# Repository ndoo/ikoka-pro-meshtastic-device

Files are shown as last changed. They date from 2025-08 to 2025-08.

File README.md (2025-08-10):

# Ikoka Pro Meshtastic Device

* Eurocard form factor
  * Half Eurocard - 100 mm × 80mm
  * All I/O in front
* Nordic nrf52840 MCU (EBYTE E73-2G4M08S1C module)
* EBYTE E22 LoRa module (22/30/33 dBm)
* Quectel L76K GPS
* Up to 1.5A solar/DC charging

## PCB Renders

### PCB Top

top

### PCB Bottom

bottom

### Rotating GIF

animation

(Rendered with [kicad-render](https://github.com/linalinn/kicad-render).)

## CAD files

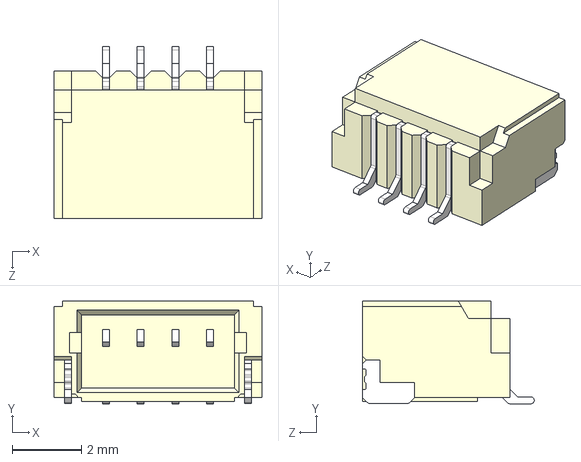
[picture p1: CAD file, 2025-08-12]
3dmodels/SM04B-SRSS-TB (LF)(SN)--3DModel-STEP-269445.STEP
6.00 x 2.96 x 4.95 mm

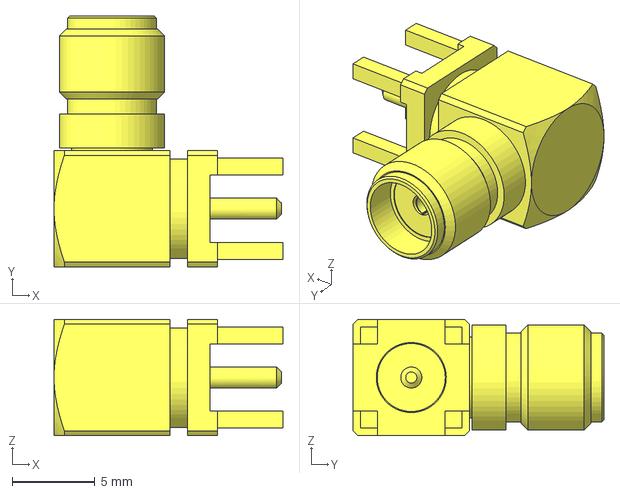
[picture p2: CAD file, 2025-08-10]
3dmodels/SMA-J-P-H-RA-TH1.stp
13.8 x 15.1 x 7.00 mm

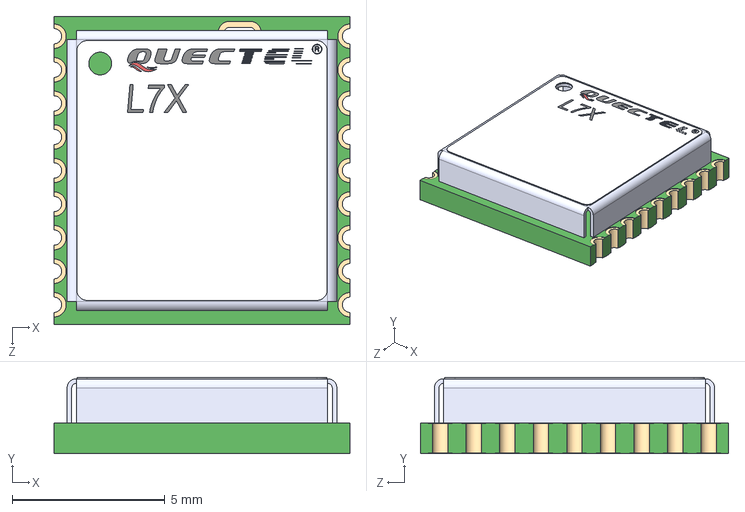
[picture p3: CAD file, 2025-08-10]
3dmodels/L76.STEP
9.70 x 2.49 x 10.1 mm

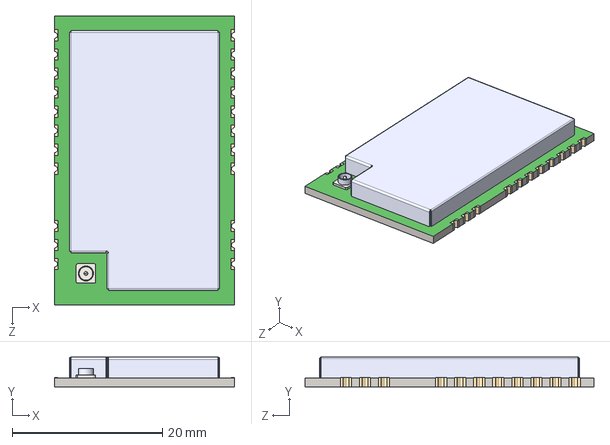
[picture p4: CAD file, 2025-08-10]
3dmodels/E22-900M30S.step
24.0 x 3.97 x 38.5 mm

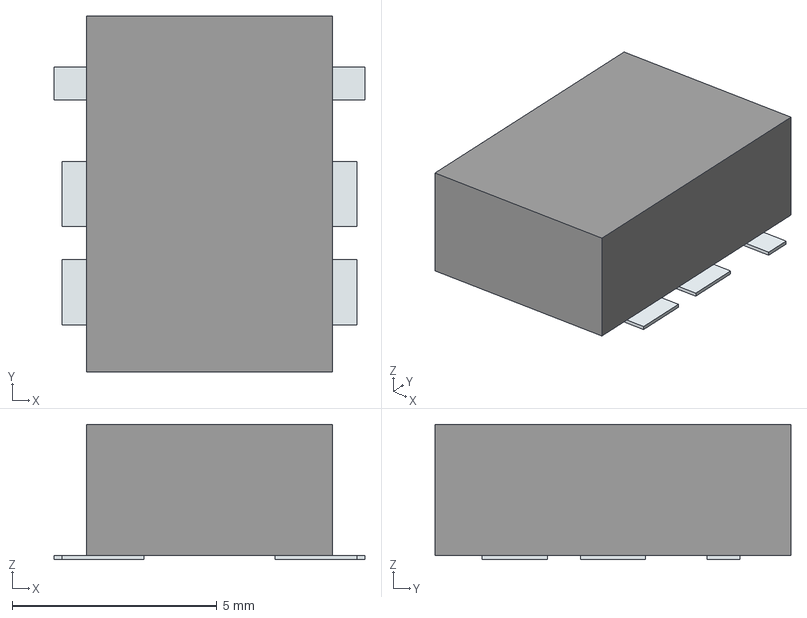
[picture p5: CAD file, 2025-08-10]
3dmodels/DBP.915.V.A.30.stp
7.60 x 8.70 x 3.30 mm
Pins

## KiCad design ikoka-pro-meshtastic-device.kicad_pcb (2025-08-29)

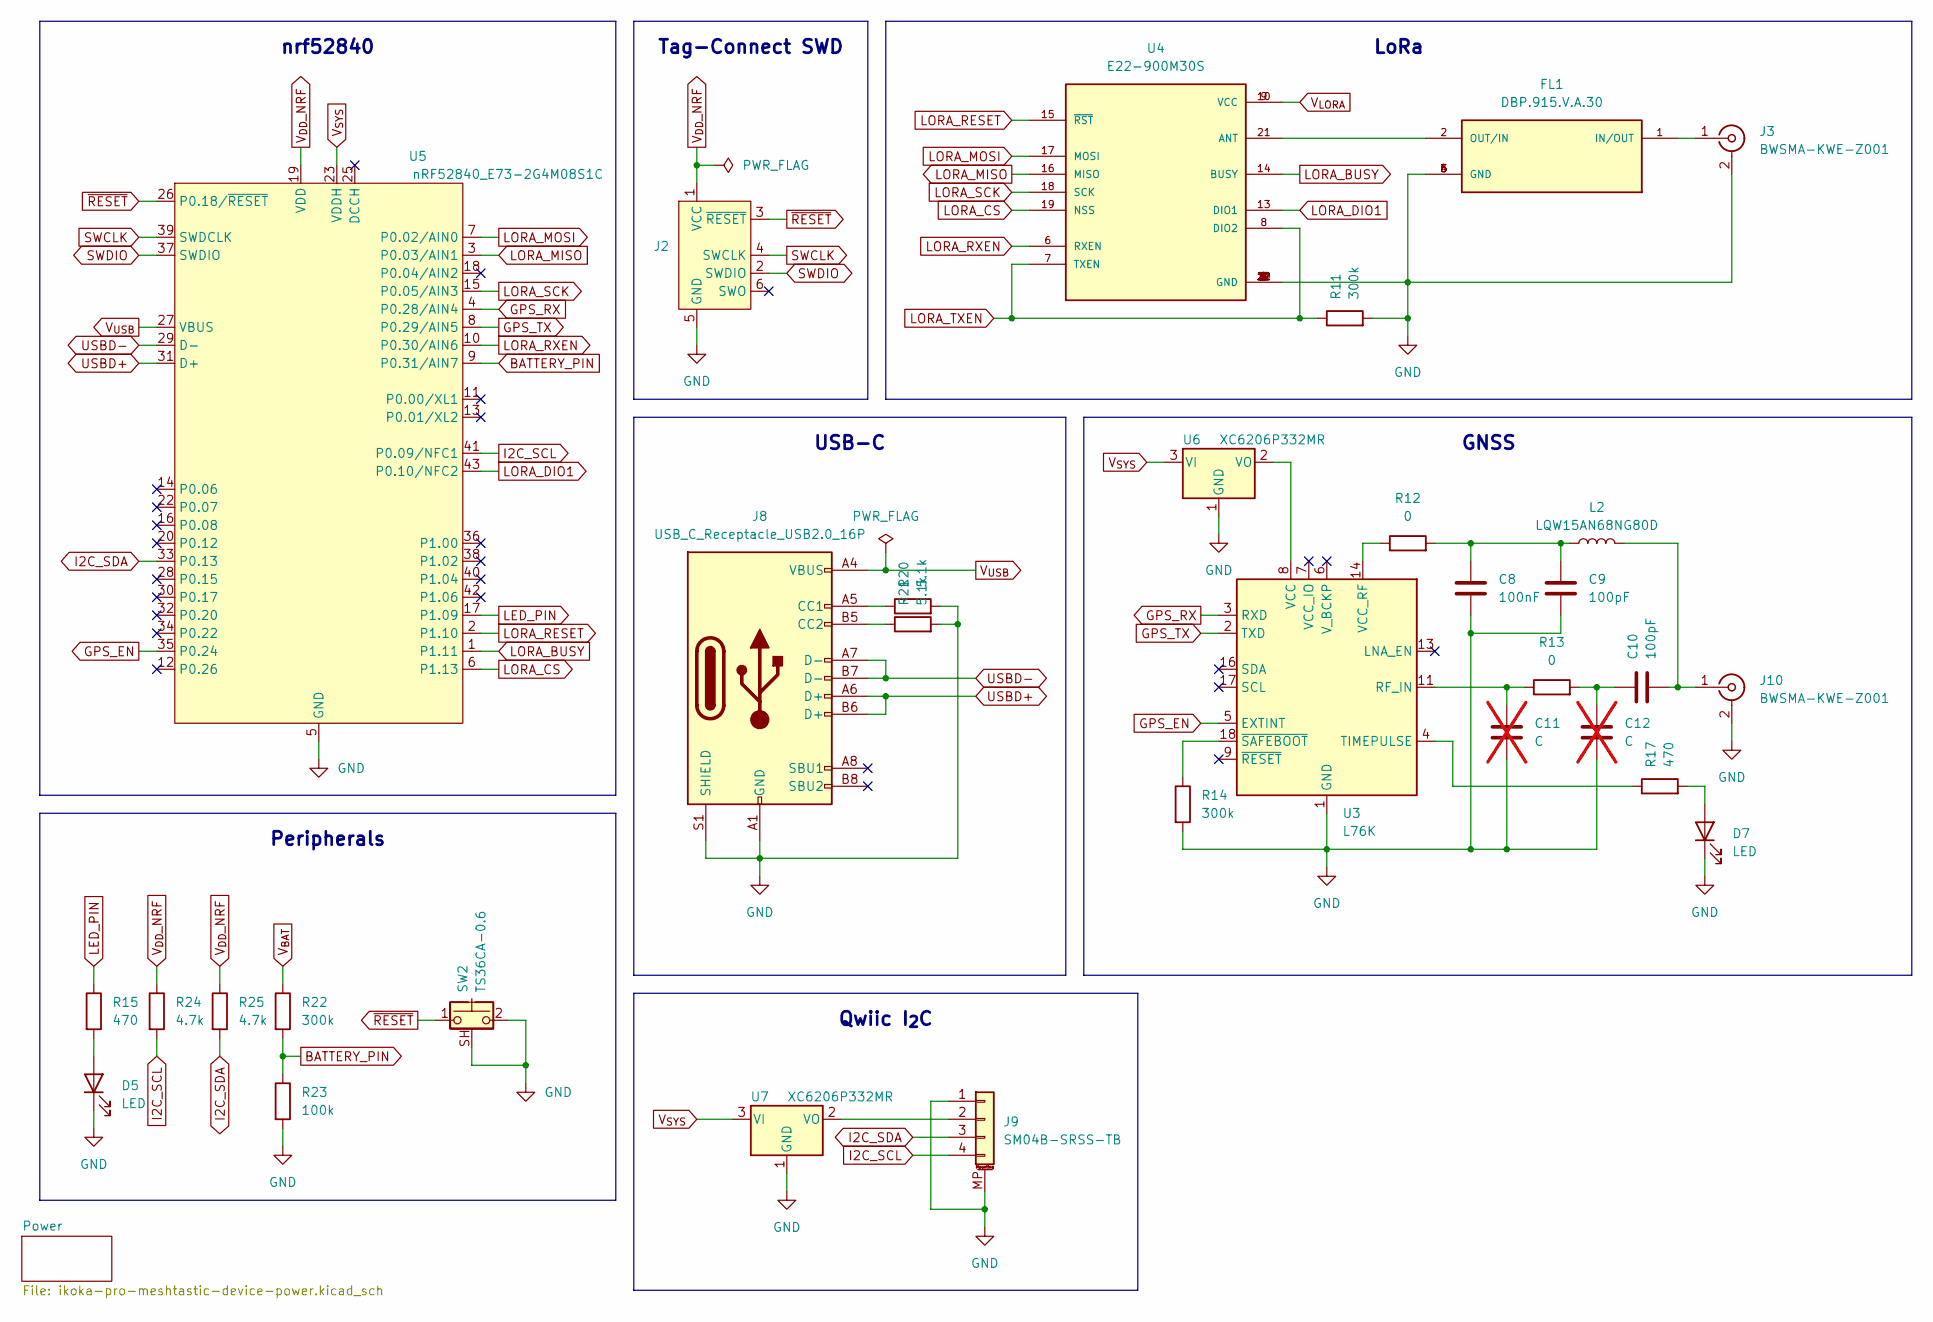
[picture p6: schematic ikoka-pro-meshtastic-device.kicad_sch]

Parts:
C8: 100nF; C_0402_1005Metric; MPN CL10A226MQ8NRNC; LCSC C307331
C9, C10: 100pF; C_0402_1005Metric; MPN CL10A226MQ8NRNC; LCSC C1546
C11, C12: C; C_0402_1005Metric; MPN CL10A226MQ8NRNC; LCSC C59461; not fitted
D5, D7: LED; LED_0603_1608Metric; LCSC C2290
FL1: DBP.915.V.A.30; FIL_DBP.915.V.A.30; PARTREV SPE-17-8-060/B/AW; LCSC C3155564
J2: Conn_ARM_JTAG_SWD_10; CON_TC2030_outlined
J3, J10: BWSMA-KWE-Z001; SMA_BAT_Wireless_BWSMA-KWE-Z001; LCSC C496551
J8: USB_C_Receptacle_USB2.0_16P; USB_C_Receptacle_G-Switch_GT-USB-7051x; LCSC C2843970
J9: SM04B-SRSS-TB; JST_SH_SM04B-SRSS-TB_1x04-1MP_P1.00mm_Horizontal; LCSC C160404
L2: LQW15AN68NG80D; L_0402_1005Metric; LCSC C3221844
R11, R14, R22: 300k; R_0402_1005Metric; LCSC C25774
R12, R13: 0; R_0402_1005Metric; LCSC C17168
R15, R17: 470; R_0402_1005Metric; LCSC C25117
R20, R21: 5.1k; R_0402_1005Metric; LCSC C25905
R23: 100k; R_0402_1005Metric; LCSC C25741
R24, R25: 4.7k; R_0402_1005Metric; LCSC C25900
SW2: TS36CA-0.6; SW_SPST_TS36CA-0.6; LCSC C2906288
U3: L76K; ublox_MAX; LCSC C2916234
U4: E22-900M30S; XCVR_E22-900M30S; PARTREV 1.2; LCSC C411294
U5: nRF52840_E73-2G4M08S1C; LCSC C356849
U6, U7: XC6206P332MR; SOT-23-3; LCSC C5446

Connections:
BATTERY_PIN: R22.2, R23.1, U5.9 (P0.31/AIN7)
GND: C8.2, C9.2, C11.2, C12.2, D5.1 (K), D7.1 (K), FL1.3 (GND), FL1.4 (GND), FL1.5 (GND), FL1.6 (GND), J2.5 (GND), J3.2 (Ext), J8.A1 (GND), J8.A12 (GND), J8.B1 (GND), J8.B12 (GND), J8.S1 (SHIELD), J9.1, J9.MP (MountPin), J10.2 (Ext), R11.2, R14.2, R20.2, R21.2, R23.2, SW2.2, SW2.SH (B), U3.1 (GND), U3.10 (GND), U3.12 (GND), U4.1 (GND), U4.2 (GND), U4.3 (GND), U4.4 (GND), U4.5 (GND), U4.11 (GND), U4.12 (GND), U4.20 (GND), U4.22 (GND), U5.5 (GND), U5.21 (GND), U5.24 (GND), U6.1 (GND), U7.1 (GND); also elsewhere on the board
GPS_EN: U3.5 (EXTINT), U5.35 (P0.24)
GPS_RX: U3.3 (RXD), U5.4 (P0.28/AIN4)
GPS_TX: U3.2 (TXD), U5.8 (P0.29/AIN5)
I2C_SCL: J9.4, R24.2, U5.41 (P0.09/NFC1)
I2C_SDA: J9.3, R25.2, U5.33 (P0.13)
LED_PIN: R15.1, U5.17 (P1.09)
LORA_BUSY: U4.14 (BUSY), U5.1 (P1.11)
LORA_CS: U4.19 (NSS), U5.6 (P1.13)
LORA_DIO1: U4.13 (DIO1), U5.43 (P0.10/NFC2)
LORA_MISO: U4.16 (MISO), U5.3 (P0.03/AIN1)
LORA_MOSI: U4.17 (MOSI), U5.7 (P0.02/AIN0)
LORA_RESET: U4.15 (~RST), U5.2 (P1.10); also elsewhere on the board
LORA_RXEN: U4.6 (RXEN), U5.10 (P0.30/AIN6)
LORA_SCK: U4.18 (SCK), U5.15 (P0.05/AIN3)
LORA_TXEN: R11.1, U4.7 (TXEN), U4.8 (DIO2)
unnamed: C8.1, C9.1, L2.1, R12.2
unnamed: C10.1, C12.1, R13.2
unnamed: D5.2 (A), R15.2
unnamed: D7.2 (A), R17.2
unnamed: FL1.1 (IN/OUT), J3.1 (In)
unnamed: FL1.2 (OUT/IN), U4.21 (ANT)
unnamed: J8.A5 (CC1), R20.1
unnamed: J8.B5 (CC2), R21.1
unnamed: J9.2, U7.2 (VO)
unnamed: C10.2, J10.1 (In), L2.2
unnamed: C11.1, R13.1, U3.11 (RF_IN)
unnamed: R17.1, U3.4 (TIMEPULSE)
unnamed: U3.8 (VCC), U6.2 (VO)
unnamed: R12.1, U3.14 (VCC_RF)
unnamed: R14.1, U3.18 (~SAFEBOOT)
SWCLK: J2.4 (SWCLK), U5.39 (SWDCLK)
SWDIO: J2.2 (SWDIO), U5.37 (SWDIO)
USBD+: J8.A6 (D+), J8.B6 (D+), U5.31 (D+)
USBD-: J8.A7 (D-), J8.B7 (D-), U5.29 (D-)
V_{BAT}: R22.1; also elsewhere on the board
V_{DD}_NRF: J2.1 (VCC), R24.1, R25.1, U5.19 (VDD)
V_{LORA}: U4.9 (VCC), U4.10 (VCC); also elsewhere on the board
V_{SYS}: U5.23 (VDDH), U6.3 (VI), U7.3 (VI); also elsewhere on the board
V_{USB}: J8.A4 (VBUS), J8.A9 (VBUS), J8.B4 (VBUS), J8.B9 (VBUS), U5.27 (VBUS)
~RESET: J2.3 (~RESET), SW2.1, U5.26 (P0.18/~RESET)

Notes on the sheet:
LoRa
Peripherals
USB-C
nrf52840
GNSS
Qwiic I_{2}C
Tag-Connect SWD

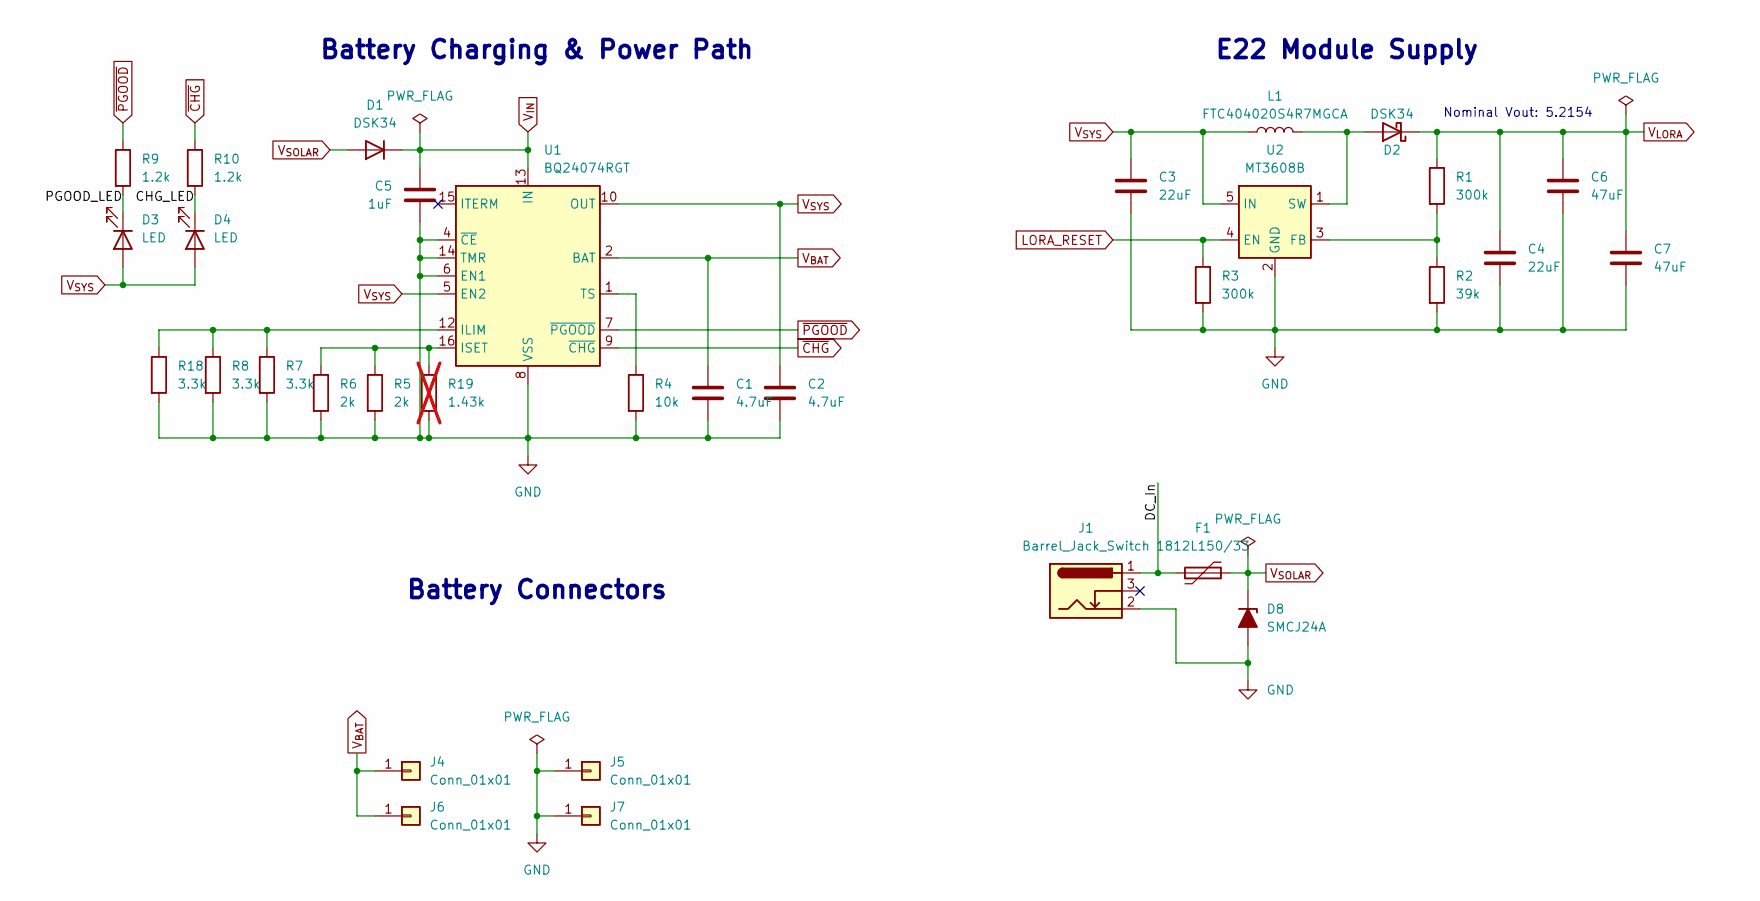
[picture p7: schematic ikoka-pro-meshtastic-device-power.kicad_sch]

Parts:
C1, C2: 4.7uF; C_0402_1005Metric; MPN CL10A226MQ8NRNC; LCSC C23733
C3: 22uF; C_0603_1608Metric; LCSC C59461
C4: 22uF; C_0603_1608Metric; MPN CL10A226MQ8NRNC; LCSC C59461
C5: 1uF; C_0402_1005Metric; MPN CL10A226MQ8NRNC; LCSC C52923
C6, C7: 47uF; C_0805_2012Metric; MPN CL10A226MQ8NRNC; LCSC C16780
D1, D2: DSK34; D_SOD-123F; LCSC C7502709
D3, D4: LED; LED_0603_1608Metric; LCSC C2290
D8: SMCJ24A; D_SMC; LCSC C19077604
F1: 1812L150/33; Fuse_1812_4532Metric; LCSC C42369221
J1: Barrel_Jack_Switch; BarrelJack_Horizontal; LCSC C16214
J4, J5, J6, J7: Conn_01x01; BatteryClip_Keystone_54_D16-19mm; LCSC C2685232
L1: FTC404020S4R7MGCA; L_Changjiang_FTC404020S; LCSC C39676072
R1: 300k; R_0402_1005Metric; MPN 0603WAF1502T5E; LCSC C25774
R2: 39k; R_0402_1005Metric; MPN 0603WAF1871T5E; LCSC C25783
R3: 300k; R_0402_1005Metric; LCSC C25774
R4: 10k; R_0402_1005Metric; LCSC C25744
R5, R6: 2k; R_0402_1005Metric; LCSC C4109
R7, R8, R18: 3.3k; R_0402_1005Metric; LCSC C25890
R9, R10: 1.2k; R_0402_1005Metric; LCSC C25862
R19: 1.43k; R_0402_1005Metric; LCSC C25867; not fitted
U1: BQ24074RGT; VQFN-16-1EP_3x3mm_P0.5mm_EP1.6x1.6mm; LCSC C54313
U2: MT3608B; SOT-23-6; LCSC C19189893

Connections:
/Power/CHG_LED: D4.1 (K), R10.2
/Power/DC_In: F1.1, J1.1
/Power/PGOOD_LED: D3.1 (K), R9.2
GND: C1.2, C2.2, C3.2, C4.2, C5.2, C6.2, C7.2, D8.2 (A), J1.2, J5.1, J7.1, R2.2, R3.2, R4.2, R5.2, R6.2, R7.2, R8.2, R18.2, R19.2, U1.4 (~CE), U1.6 (EN1), U1.8 (VSS), U1.14 (TMR), U1.17 (VSS), U2.2 (GND); also elsewhere on the board
LORA_RESET: R3.1, U2.4 (EN); also elsewhere on the board
unnamed: D2.2 (A), L1.1, U2.1 (SW)
unnamed: R7.1, R8.1, R18.1, U1.12 (ILIM)
unnamed: R5.1, R6.1, R19.1, U1.16 (ISET)
unnamed: R4.1, U1.1 (TS)
unnamed: R1.2, R2.1, U2.3 (FB)
V_{BAT}: C1.1, J4.1, J6.1, U1.2 (BAT), U1.3 (BAT); also elsewhere on the board
V_{IN}: C5.1, D1.1 (K), U1.13 (IN)
V_{LORA}: C4.1, C6.1, C7.1, D2.1 (K), R1.1; also elsewhere on the board
V_{SOLAR}: D1.2 (A), D8.1 (K), F1.2
V_{SYS}: C2.1, C3.1, D3.2 (A), D4.2 (A), L1.2, U1.5 (EN2), U1.10 (OUT), U1.11 (OUT), U2.5 (IN); also elsewhere on the board
~CHG: R10.1, U1.9 (~CHG)
~PGOOD: R9.1, U1.7 (~PGOOD)

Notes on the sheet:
E22 Module Supply
Battery Connectors
Battery Charging & Power Path
Nominal Vout: 5.2154

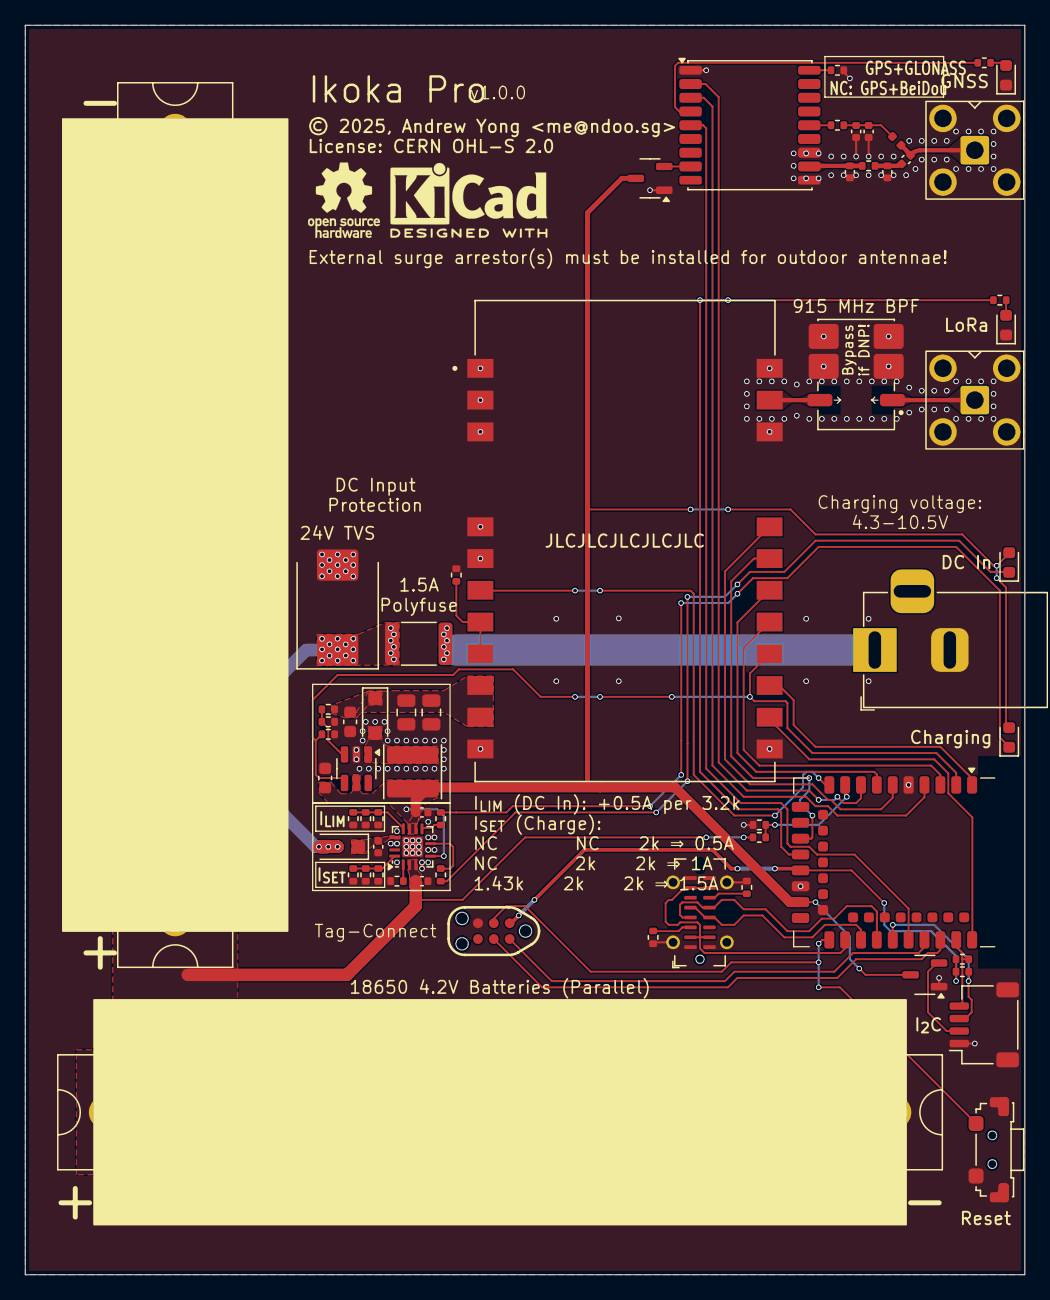
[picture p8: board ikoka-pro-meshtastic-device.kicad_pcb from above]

Board: 2 copper layers, 80.0 x 100.0 mm, 65 parts (0 on the bottom side), 54 nets.

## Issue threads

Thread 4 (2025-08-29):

Taoglas DBP.915.V.A.30 footprint is wrong

ndoo, 2025-08-29:
The antenna trace is off by almost 1mm. It can be reworked manually to align it, but this needs to be fixed on the pcbnew.

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

Closed 2025-08-29.

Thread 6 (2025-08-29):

Put soldermask back on RF traces because they may short against BWSMA-KWE-Z001 which does not have a clearance gap to the PCB

ndoo, 2025-08-29:

Closed 2025-08-29.

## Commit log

2025-08-10 docs: Update README.md and add GitHub workflow for PCB images
2025-08-11 feat: Move SWD pads further away from USB-C and battery
    [ikoka-pro-meshtastic-device.kicad_pcb, ikoka-pro-meshtastic-device.kicad_sch]
2025-08-11 feat(pcbnew): Use R_1812_4532Metric 3dmodel for fuse
    [ikoka-pro-meshtastic-device.kicad_pcb]
2025-08-12 feat: I2C and 100k+300k VBAT divider
    Fixes #1
    [SM04B-SRSS-TB (LF)(SN)--3DModel-STEP-269445.STEP, ikoka-pro-meshtastic-device-power.kicad_sch, ikoka-pro-meshtastic-device.kicad_pcb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]
2025-08-12 chore: v0.9.0 and JLCPCB order placeholder silkscreen
    [ikoka-pro-meshtastic-device.kicad_pcb]
2025-08-12 fix: 4.7kΩ I2C pull-up JLCPCB part selection
    [ikoka-pro-meshtastic-device.kicad_pcb, ikoka-pro-meshtastic-device.kicad_sch]
2025-08-13 fix: Update TS36CA footprint according to JLCPCB DFM
    [ikoka-pro-meshtastic-device.kicad_pcb]
2025-08-15 fix: Soldermask between pi network on LoRa trace
    [ikoka-pro-meshtastic-device.kicad_pcb]
2025-08-29 fix: Swap GPS Tx and Rx (fixes #5)
    [ikoka-pro-meshtastic-device.kicad_pcb, ikoka-pro-meshtastic-device.kicad_sch]
2025-08-29 fix(pcbnew): Put soldermask back on RF traces (fixes #6)
    [ikoka-pro-meshtastic-device.kicad_pcb]
2025-08-29 fix(pcbnew): Redraw footprint for Taoglas DBP.915.V.A.30 (fixes #4)
    - Silkscreen re-drawn following KLC guidelines and correctly aligned to part
    - Courtyard re-drawn following KLC guidelines and correctly aligned to part
    - Use 0.25mm roundrects for pads
    - Remove custom soldermask and paste in favor of KiCad pad defaults
    [ikoka-pro-meshtastic-device.kicad_pcb]
2025-08-29 fix: Use correct resistor values for ILIM and default to 1.5A (fixes #7)
    [ikoka-pro-meshtastic-device-power.kicad_sch, ikoka-pro-meshtastic-device.kicad_pcb]
2025-08-29 fix: Change USB-C CC resistors from 510Ω to 5.1kΩ (fixes #8)
    [ikoka-pro-meshtastic-device.kicad_pcb, ikoka-pro-meshtastic-device.kicad_sch]
2025-08-29 chore: v1.0.0 silkscreen
    [ikoka-pro-meshtastic-device.kicad_pcb]

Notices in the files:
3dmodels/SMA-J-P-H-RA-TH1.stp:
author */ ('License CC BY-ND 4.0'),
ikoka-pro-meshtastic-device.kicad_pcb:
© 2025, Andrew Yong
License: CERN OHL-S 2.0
